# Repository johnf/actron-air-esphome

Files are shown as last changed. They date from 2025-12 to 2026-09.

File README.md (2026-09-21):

# Actron Air ESPHome Integration for Home Assistant

An ESPHome external component for reading and decoding pulse trains from the
Actron Air ESP32 keypad display, plus a Home Assistant integration with climate
entity and custom Lovelace card.

## Key Features

- **Interrupt-driven reading**: Accurate pulse train capture
- **40-bit decoding**: Full status from keypad display
- **Temperature display**: 7-segment decoder for setpoint
- **18 binary sensors**: Mode, fan, zones, timers
- **Error tracking**: Bit count for monitoring reliability
- **Type-safe config**: ESPHome validation for all settings
- **Climate entity**: Full HVAC control with zone presets
- **Custom Lovelace card**: Retro keypad-style control interface

## Hardware Requirements

- ESP32 (ESP-IDF framework, circuit below uses an ESP32-C3 Super Mini)
- GPIO pin for pulse train input
- Connection to air conditioner keypad display output
- MCP4725 or MCP4726 DAC (I2C) for keypad button emulation
- HW133 DC-DC converter to power the ESP from the keypad
- BC548 NPN transistor
- Resistors: 22kΩ, 4.7kΩ, 1.0kΩ (0.5W or higher)
- Diode: 1N5817
- Capacitor: 1000µF (25V or higher)

See the [forum thread](https://community.home-assistant.io/t/actron-aircon-esp32-controller-help/609062)
for detailed build instructions and wiring diagrams.

## Compatible Systems

This integration works with Actron Air ducted systems that use the older-style
wall controllers with a 4-wire interface (SENS, KEY, COMM, POWER).

### Wall Controllers

| Controller | Status | Notes |
|---|---|---|
| LM24 | Confirmed | Multi-zone controller |
| LM7 / LM7-2W / LM7-2G | Community reported | 7-day programmable, up to 8 zones |
| LM7-D | Community reported | Ultima Zone Control Master |
| AM7 | Community reported | Original older controller |

### Air Conditioner Systems

**Compatible:**

- SRA series (e.g., SRA22C, SRA25C) - older multi-zone ducted systems
- SRD series (e.g., SRD175C, SRD22C) - older ducted systems
- ESP Plus, ESP Platinum, ESP Ultima with LM7/LM24 controllers
- Classic series (SRG models) with LM7/LM24 controllers

**Not compatible:**

- Systems with QUE controllers (different architecture)
- Systems with ActronConnect/ACM WiFi modules (post-2013)
- Serene Series with Easy Connect app

## Installation

This project has two parts:

1. **ESPHome component** - Runs on your ESP32 to read the keypad and control the AC
2. **Home Assistant integration** - Provides climate entity and Lovelace card

**Set up the ESPHome device first**, then install the Home Assistant integration.

### Step 1: ESPHome Device Setup

See [ESPHome Configuration](#esphome-configuration) below for detailed setup instructions.
The quickest way is to use the ESPHome package - just copy
[example_actron_air_keypad.yaml](example_actron_air_keypad.yaml) and customise for your setup.

### Step 2: Home Assistant Integration

Once your ESPHome device is running, install the integration:

#### HACS (Recommended)



Or manually:

1. Open HACS in Home Assistant
2. Go to "Integrations" section
3. Click the three dots menu and select "Custom repositories"
4. Add `https://github.com/johnf/actron-air-esphome` with category "Integration"
5. Install "Actron Air ESPHome"
6. Restart Home Assistant
7. Go to Settings > Devices & Services > Add Integration
8. Search for "Actron Air ESPHome" and configure

The integration will automatically register the Lovelace card.

#### Manual Installation

1. Copy the `custom_components/actron_air_esphome` folder to your Home Assistant `config/custom_components/` directory
2. Restart Home Assistant
3. Go to Settings > Devices & Services > Add Integration
4. Search for "Actron Air ESPHome" and configure

## Lovelace Card Usage

Actron Air Card

Add the card to your dashboard:

```yaml
type: custom:actron-air-esphome-card
entity_prefix: actron_air
```

### Card Configuration Options

| Option | Type | Default | Description |
|---|---|---|---|
| `entity_prefix` | string | **required** | Prefix for ESPHome entities (e.g., `actron_air`) |
| `name` | string | - | Card title (optional) |
| `show_timer` | boolean | `true` | Show timer controls |
| `show_zones` | boolean | `true` | Show zone buttons |
| `zone_count` | number | `4` | Number of zones to display (1-7) |
| `zones` | array | - | Custom zone names |

### Full Configuration Example

```yaml
type: custom:actron-air-esphome-card
entity_prefix: actron_air
name: Air Conditioning
show_timer: true
show_zones: true
zone_count: 4
zones:
  - name: Bedrooms
  - name: Living Room
  - name: Kitchen
  - name: Office
```

### Expected Entity Names

The card expects entities with the following naming pattern based on your `entity_prefix`:

**Sensors:**

- `sensor.{prefix}_setpoint_temperature`

**Switches:**

- `switch.{prefix}_power`
- `switch.{prefix}_zone_1` through `switch.{prefix}_zone_8`

**Binary Sensors:**

- `binary_sensor.{prefix}_cool`
- `binary_sensor.{prefix}_heat`
- `binary_sensor.{prefix}_auto`
- `binary_sensor.{prefix}_run`
- `binary_sensor.{prefix}_fan_low`
- `binary_sensor.{prefix}_fan_mid`
- `binary_sensor.{prefix}_fan_high`
- `binary_sensor.{prefix}_fan_continuous`
- `binary_sensor.{prefix}_inside`
- `binary_sensor.{prefix}_timer`
- `binary_sensor.{prefix}_zone_1` through `binary_sensor.{prefix}_zone_8`

**Buttons:**

- `button.{prefix}_mode`
- `button.{prefix}_fan`
- `button.{prefix}_temp_up`
- `button.{prefix}_temp_down`
- `button.{prefix}_timer`
- `button.{prefix}_timer_up`
- `button.{prefix}_timer_down`

## ESPHome Configuration

The easiest way to get started is to use the ESPHome package, which includes all
sensors, DAC controls, and button definitions. See
[example_actron_air_keypad.yaml](example_actron_air_keypad.yaml) for a complete example.

### Quick Start (Using Package)

```yaml
packages:
  actron_air: github://johnf/actron-air-esphome/actron_air_keypad.yaml@main

esphome:
  name: "my-aircon"
  friendly_name: My Air Conditioner

wifi:
  ssid: !secret wifi_ssid
  password: !secret wifi_password

# Enable auto-discovery in Home Assistant
mdns:
  services:
    - service: "_actron_air"
      protocol: "_tcp"
      port: 6053
      txt:
        version: "1.0.0"
        name: "my-aircon"
```

That's it! The package includes everything you need:

- All 7 zones (remove unused ones with `!remove` if desired)
- DAC output for button emulation
- All binary sensors, switches, and buttons
- Configurable GPIO pins and voltage calibration via substitutions

### Customising the Package

Override any defaults by adding a `substitutions` section before the package:

```yaml
substitutions:
  gpio_keypad_pin: "GPIO32"    # Pin for keypad signal
  gpio_i2c_sda: "GPIO21"       # I2C SDA pin
  gpio_i2c_scl: "GPIO22"       # I2C SCL pin
  dac_output_address: "0x60"   # MCP4725 DAC I2C address
  # Voltage calibration (millivolts)
  voltage_zone_1: "725.0"
  voltage_zone_2: "663.0"
  # ... see actron_air_keypad.yaml for all options

packages:
  actron_air: github://johnf/actron-air-esphome/actron_air_keypad.yaml@main
```

### Removing Unused Zones

If you have fewer than 7 zones, you can remove the unused ones:

```yaml
packages:
  actron_air: github://johnf/actron-air-esphome/actron_air_keypad.yaml@main

# Remove zones 5-8 for a 4-zone system
switch:
  - id: !remove zone_5_switch
  - id: !remove zone_6_switch
  - id: !remove zone_7_switch
  - id: !remove zone_8_switch

  - id: !remove zone_5
  - id: !remove zone_6
  - id: !remove zone_7
  - id: !remove zone_8
```

### Manual Configuration (Without Package)

If you prefer more control, you can use the external component directly:

```yaml
external_components:
  - source:
      type: git
      url: https://github.com/johnf/actron-air-esphome
      ref: main
    components: [actron_air_esphome]

actron_air_esphome:
  pin: GPIO32

sensor:
  - platform: actron_air_esphome
    setpoint_temp:
      name: "Temperature"

binary_sensor:
  - platform: actron_air_esphome
    cool:
      name: "Cool Mode"
    heat:
      name: "Heat Mode"
    fan_high:
      name: "Fan High"
    zone_1:
      name: "Zone 1"
    zone_2:
      name: "Zone 2"
```

## Climate Entity

The Home Assistant integration provides a climate entity with:

- **HVAC Modes**: Off, Cool, Heat, Auto, Fan Only
- **Fan Modes**: High, Medium, Low, High Cont, Medium Cont, Low Cont, Off
- **Zone Presets**: Individual zones and "All Zones"
- **Optional**: Current temperature and humidity from external sensors

Configure via Settings > Devices & Services after installing the integration.

## Available ESPHome Sensors

### Numeric Sensors (`sensor` platform)

- `setpoint_temp` - Temperature from 7-segment display (C)
- `error_count` - Error counter for monitoring

### Status Sensors (`binary_sensor` platform)

- **Mode**: `cool`, `heat`, `auto_mode`, `run`
- **Fan**: `fan_high`, `fan_mid`, `fan_low`, `fan_cont`
- **Zones**: `zone_1` through `zone_8`
- **Other**: `inside`, `timer`

### Debug Sensors (`text_sensor` platform)

- `bit_string` - Raw 40-bit pulse train (internal use)

## How It Works

### Wires

There are 4 wires inside the wall unit that connect to the main supply:

- SENS - sensor line is directly connected to a thermistor
- KEY - connected to the keypad, it changes resistance to a different value
  when keys are pressed. This drops the voltage from 5V to different levels
- COMM - ground
- POWER - 19V and also data line that gets shifted into the LED. The protocol
  in this wire is quite simple: Data is transmitted every 200ms or so. It starts
  with a 16V->0V transition, followed by 41 other pulses, a zero or a one is
  determined by the time between the pulses. Each value is then shifted through
  the leds in the board.

### Pulse Train Decoding

1. An interrupt handler captures falling edges on the ADC pin
2. Timing between edges determines if the pulse represents a '0' or '1'
3. 40 bits are collected to form a complete frame
4. The frame is decoded to extract display and LED status
5. Changes are published to Home Assistant sensors

## Circuit Diagrams

The circuit connects the ESP32 to the Actron Air keypad interface. Fritzing source
files are available in the [fritzing/](fritzing/) directory.

### Schematic

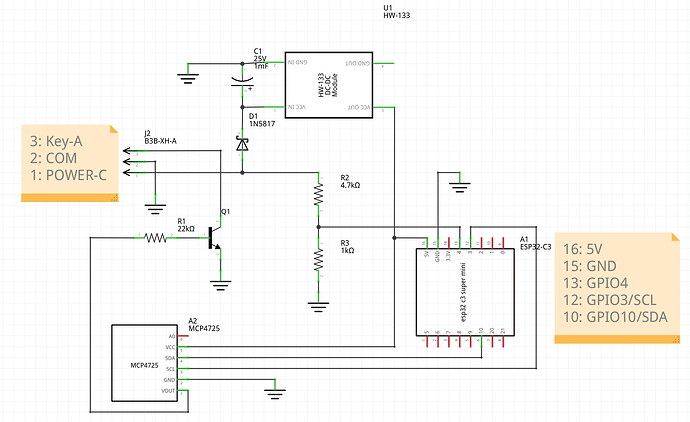
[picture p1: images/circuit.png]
Circuit Schematic


### Veroboard Layout

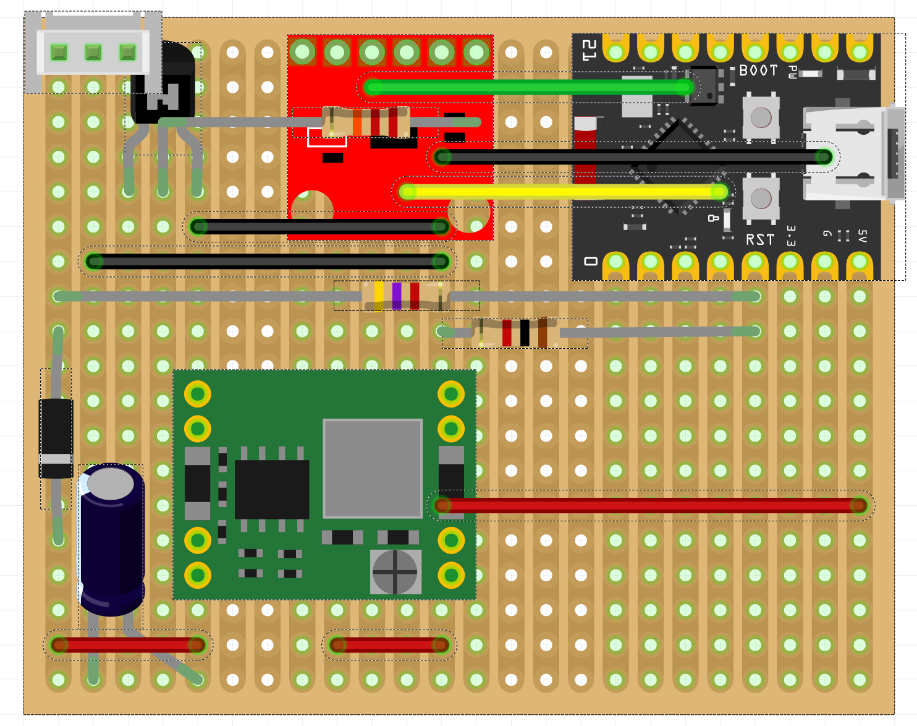
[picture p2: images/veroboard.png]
Veroboard Layout


## Troubleshooting

### No data received

- Check ADC pin connection
- Verify pulse train voltage levels
- Monitor `error_count` sensor for errors

### Incorrect temperature readings

- Check 7-segment wiring/decoding
- Look at `bit_string` for raw data
- Verify display is showing temperature

### Compile errors

- Ensure ESP-IDF framework is selected
- Check all Python files are present
- Validate YAML indentation

### Card not showing

- Clear browser cache
- Check browser console for errors
- Verify the resource is loaded in Settings > Dashboards > Resources

---

**Need Help?**

- Check ESPHome logs: `esphome logs your-device.yaml`
- Validate config: `esphome config your-device.yaml`
- Review example_actron_air_keypad.yaml for complete setup

## License

MIT License - Feel free to use and modify

## Thanks

This builds on the work of many others:

- <https://community.home-assistant.io/t/actron-aircon-esp32-controller-help/609062>
- <https://github.com/kursancew/actron-air-wifi>
- <https://github.com/brentk7/Actron-Keypad>
- <https://github.com/cjd/Actron-Keypad>
- <https://github.com/LaughingLogic/Actron-Keypad>

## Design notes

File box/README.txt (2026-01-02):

Box 02 (with rectangular and hexagonal ventilation holes) by jorgecasas on Thingiverse: https://www.thingiverse.com/thing:2004687

Modified by John Ferlito for this project

Summary:
Small box (parametrizable), with logo and ventilation holes (grid rectangular and hexagonal)

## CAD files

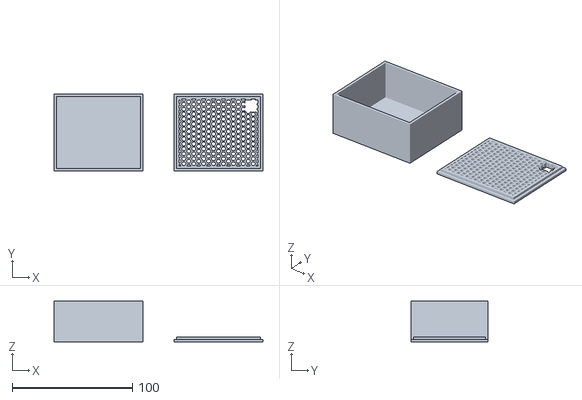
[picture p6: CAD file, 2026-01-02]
box/box-wemos-iternova.stl
174.0 x 64.0 x 34.0

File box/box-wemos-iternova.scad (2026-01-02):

// Dimensions
box_thick = 2;
box_width = 70 + 2 *  box_thick;
box_height = 60 + 2 *  box_thick;
box_depth = 30 + 2 *  box_thick;
connector_height = 10;
connector_width = 10;

// Bottom
difference() {
    // Parte exterior - interior (caja hueca)
    cube([box_width,  box_height,  box_depth]);
    translate([box_thick,  box_thick, 2 *  box_thick])
      cube([box_width - 2 * box_thick, box_height - 2 * box_thick, box_depth ]);
}

// Top
translate([100,0,0]) {
    difference() {
        // Tapa + reborde de tapa
        union() {
            cube([box_width, box_height, box_thick]);
            translate([box_thick, box_thick, 0])
              cube([box_width - 2 * box_thick, box_height- 2 * box_thick, 2 * box_thick]);
        }

        // Grid hexagonal tapa
        translate([box_thick + 1, box_thick + 1, -1])
          grid_hexagonal(box_width - (2 * box_thick), box_height - (2 * box_thick ), box_thick + 2, 16);
    
        // Connector hole - top right corner (with margin from edge)
translate([box_width - connector_width - box_thick - 3, box_height - connector_height - box_thick - 3, -1])
  cube([connector_width, connector_height, 2 * box_thick + 2]);
    }  
}
       

module grid_hexagonal(width, height, depth , hexagons_width) {    
    separation = (width / hexagons_width ) / 2.25;
    intersection() {
       // cube([width,height,depth], center = false);
        translate( [ separation / 2, separation / 2, 0] ) intersection() {
            array_hexagons(width - 4, height - 4, depth + 2, hexagons_width );
            cube([width - 4,height - 4,depth + 2], center = false);
        }
    }
}

/**
 * Create an array of hexagons
 */
module array_hexagons(width, height, depth, hexagons_width) {    
    separation = (width / hexagons_width);
    hexagons_height = (hexagons_width * height / width);
    radio = separation / 2.25;
    
    for( x = [ 0 : 1 : hexagons_width])
        for( y = [ 0 : 1 : hexagons_height ])
            translate([(x * separation), ( y + ( x % 2 )/2 ) * separation ,0])
                cylinder(h = depth, r1 = radio, r2 = radio, center = false , $fn = 6);

}

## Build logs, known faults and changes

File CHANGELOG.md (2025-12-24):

## [0.1.4](https://github.com/johnf/actron-air-esphome/compare/v0.1.3...v0.1.4) (2025-12-24)

### Bug Fixes

* modify load path for card registration [#3](https://github.com/johnf/actron-air-esphome/issues/3) ([3b6d908](https://github.com/johnf/actron-air-esphome/commit/3b6d9087fcef42e9b121fa2ee745dae154fa78ca))
* zone rendering location ([75965d7](https://github.com/johnf/actron-air-esphome/commit/75965d7d02e8ce8f1cc379385592dbc777271b5d))

## [0.1.3](https://github.com/johnf/actron-air-esphome/compare/v0.1.2...v0.1.3) (2025-12-24)

### Bug Fixes

* add integration type ([00d6ca0](https://github.com/johnf/actron-air-esphome/commit/00d6ca014bed215584a0997ca12084c9be4959b6))
* keep manifest.json updated ([5e00df8](https://github.com/johnf/actron-air-esphome/commit/5e00df8b643e7f9c56efc840927adfa06ade6363))

## [0.1.2](https://github.com/johnf/actron-air-esphome/compare/v0.1.1...v0.1.2) (2025-12-19)

### Bug Fixes

* be consistent in zone naming ([7a38b1e](https://github.com/johnf/actron-air-esphome/commit/7a38b1e8fe5cabb56431b40378be47fccf80169e))

## [0.1.1](https://github.com/johnf/actron-air-esphome/compare/v0.1.0...v0.1.1) (2025-12-19)

### Bug Fixes

* **ci:** use gh CLI to upload zip to existing release ([30d855a](https://github.com/johnf/actron-air-esphome/commit/30d855a07f12d564fcc0fdb51098d9927c0fe18c))

## [0.1.0](https://github.com/johnf/actron-air-esphome/compare/v0.0.14...v0.1.0) (2025-12-19)

### Features

* **esphome:** convert configuration to reusable package ([a987096](https://github.com/johnf/actron-air-esphome/commit/a987096c770cb002f84c5b46585b0af0b646708a))

## [0.0.14](https://github.com/johnf/actron-air-esphome/compare/v0.0.13...v0.0.14) (2025-12-19)

### Bug Fixes

* update git URL ([f37af84](https://github.com/johnf/actron-air-esphome/commit/f37af8409b59161f5b66f513698e741b853e771b))

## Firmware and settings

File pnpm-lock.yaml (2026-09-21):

---
lockfileVersion: '9.0'

importers:

  .:
    configDependencies: {}
    packageManagerDependencies:
      pnpm:
        specifier: 12.5.1
        version: 12.5.1

packages:

  '@pnpm/exe.android-arm64@12.5.1':
    resolution: {integrity: sha512-6LGBmQuDzUmgpHSuy+haG0jrmkwFNa4EuShDZqK3cIBv4Wfb75CzjJmowkzr+iJg40vnBKMQ62t4Ko6mwsId7A==}
    cpu: [arm64]
    os: [android]

  '@pnpm/exe.android-x64@12.5.1':
    resolution: {integrity: sha512-091oCltP3Rx89yxL1Wh5rXkUXEyFzyxIzSHKRFDyDFlQkb8Ox8FaDcm+M8PNkMyqnLA+qeGOLzY7Rjj9izl1Ww==}
    cpu: [x64]
    os: [android]

  '@pnpm/exe.darwin-arm64@12.5.1':
    resolution: {integrity: sha512-r1vEMQPVjRexZMyL2HonxJoo3+nuB/+G+tg+f2PK6faRdXX1TDwevKXOxJAfqlPInTy6W/pm912+s+m0NcR4BQ==}
    cpu: [arm64]
    os: [darwin]

  '@pnpm/exe.darwin-x64@12.5.1':
    resolution: {integrity: sha512-YHwI1g2B+Y2cAEylOR31r781GWijdJL7Gy7TEn/ZpZ5v/Cuwp5/Pz0EFCgo0M2MKLafAbL/laUMGvOpAdnerAw==}
    cpu: [x64]
    os: [darwin]

  '@pnpm/exe.freebsd-x64@12.5.1':
    resolution: {integrity: sha512-sFUMHiYFs6q5syFwgaVppzhQSmqnXoJIz/YwTXIOXTDE76ndIpTRpDGAnBCBKjsaEBnqjJA/2l6hpJcNDNoMiA==}
    cpu: [x64]
    os: [freebsd]

  '@pnpm/exe.linux-arm64-musl@12.5.1':
    resolution: {integrity: sha512-zupuxYZBuBEGjUz805/4/Asq01UNziFADANt8yp+LdUjU9bbMa3xY78Bx1PsGDqBy7aiad4sdUMK8ZxH4n4gmQ==}
    cpu: [arm64]
    os: [linux]
    libc: [musl]

  '@pnpm/exe.linux-arm64@12.5.1':
    resolution: {integrity: sha512-6hbMWW2/eQo1b5wvQPe/ndLHVTH88Rav6N+ffD4/h6IuFMjWCgasFYYsFv0GrvpqREAx3SwmZSvli+0NFXqbxA==}
    cpu: [arm64]
    os: [linux]
    libc: [glibc]

  '@pnpm/exe.linux-ppc64@12.5.1':
    resolution: {integrity: sha512-Gg3maDzaE/ZFMV9HIx/BwMN0Y6QbEs13URfxmiYHtKjjLAs5wEQZRMUP87YNLYO7cNaEfbM8GRbS9vPosyD9Gw==}
    cpu: [ppc64]
    os: [linux]
    libc: [glibc]

  '@pnpm/exe.linux-riscv64@12.5.1':
    resolution: {integrity: sha512-6fgWxXYMBMsWQ8DAiRevscX4QZQjwh+FsyCj8ZOk8pMXvqeq84MqBLCmS6KckvnbdqJ+HlSVQ7fs/kd0ldwfhA==}
    cpu: [riscv64]
    os: [linux]
    libc: [glibc]

  '@pnpm/exe.linux-s390x@12.5.1':
    resolution: {integrity: sha512-nzMZruRvxDhEfYUhzu+7EmM39+82Dgagc/6hPFPqGqzXNGcIG0anuxbUxfeNtI64SHt91KuuYUmCB/inlM+Pag==}
    cpu: [s390x]
    os: [linux]
    libc: [glibc]

  '@pnpm/exe.linux-x64-musl@12.5.1':
    resolution: {integrity: sha512-kHCbegdTNHpzmPtUD4S5fqkVkqgdQR47spF9p2VPP3dIIkZl6Ytk8w0vhlAsAGgge8FmucfwX+vvPKgm0NtOCQ==}
    cpu: [x64]
    os: [linux]
    libc: [musl]

  '@pnpm/exe.linux-x64@12.5.1':
    resolution: {integrity: sha512-3PkUBYo5z4dgtlnTNIFj7QGpcDUAuqXz9WGVigPDCeccEnhGiRkWmA5102TmYJHtwJP3LfmE+ZF9PGeWhn8p9Q==}
    cpu: [x64]
    os: [linux]
    libc: [glibc]

  '@pnpm/exe.win32-arm64@12.5.1':
    resolution: {integrity: sha512-49NvjZIXHly56/PLoEDD7VphbO4N8dwMXoApElDFCpVGDNGeKlwlib1tXtnpTF6i2/XIsAj7GgatHB5KHXgBnA==}
    cpu: [arm64]
    os: [win32]

  '@pnpm/exe.win32-x64@12.5.1':
    resolution: {integrity: sha512-ePUmQFPAPJFNMwg1lelDx2PdjHqYRiF0yfg5e6qeDbPNOu97QNo557Ru/SxmCrmt8ydQWNuZXWpdEp019md5vw==}
    cpu: [x64]
    os: [win32]

  pnpm@12.5.1:
    resolution: {integrity: sha512-4/MFvHhKK8ifWtO2E4iJRw+ujSr182thIW7JHCw9ZAiXdfneOKrDMQROpA8kXLDVZmOS399lgk4ZB+9qLGLeXw==}
    engines: {node: '>=18.*'}
    hasBin: true

snapshots:

  '@pnpm/exe.android-arm64@12.5.1':
    optional: true

  '@pnpm/exe.android-x64@12.5.1':
    optional: true

  '@pnpm/exe.darwin-arm64@12.5.1':
    optional: true

  '@pnpm/exe.darwin-x64@12.5.1':
    optional: true

  '@pnpm/exe.freebsd-x64@12.5.1':
    optional: true

  '@pnpm/exe.linux-arm64-musl@12.5.1':
    optional: true

  '@pnpm/exe.linux-arm64@12.5.1':
    optional: true

  '@pnpm/exe.linux-ppc64@12.5.1':
    optional: true

  '@pnpm/exe.linux-riscv64@12.5.1':
    optional: true

  '@pnpm/exe.linux-s390x@12.5.1':
    optional: true

  '@pnpm/exe.linux-x64-musl@12.5.1':
    optional: true

  '@pnpm/exe.linux-x64@12.5.1':
    optional: true

  '@pnpm/exe.win32-arm64@12.5.1':
    optional: true

  '@pnpm/exe.win32-x64@12.5.1':
    optional: true

  pnpm@12.5.1:
    optionalDependencies:
      '@pnpm/exe.android-arm64': 12.5.1
      '@pnpm/exe.android-x64': 12.5.1
      '@pnpm/exe.darwin-arm64': 12.5.1
      '@pnpm/exe.darwin-x64': 12.5.1
      '@pnpm/exe.freebsd-x64': 12.5.1
      '@pnpm/exe.linux-arm64': 12.5.1
      '@pnpm/exe.linux-arm64-musl': 12.5.1
      '@pnpm/exe.linux-ppc64': 12.5.1
      '@pnpm/exe.linux-riscv64': 12.5.1
      '@pnpm/exe.linux-s390x': 12.5.1
      '@pnpm/exe.linux-x64': 12.5.1
      '@pnpm/exe.linux-x64-musl': 12.5.1
      '@pnpm/exe.win32-arm64': 12.5.1
      '@pnpm/exe.win32-x64': 12.5.1

---
lockfileVersion: '9.0'

settings:
  autoInstallPeers: true
  excludeLinksFromLockfile: false
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

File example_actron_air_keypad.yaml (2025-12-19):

esphome:
  name: "esphome-web-aircon"
  comment: "ESPHome configuration for AirCon Keypad"
  area: Hallway
  friendly_name: ESPHome - Actron Air
  min_version: 2025.11.0
  name_add_mac_suffix: false

esp32:
  variant: esp32
  framework:
    type: esp-idf

# Enable logging
logger:

# Enable Home Assistant API
api:

# Allow Over-The-Air updates
ota:
  - platform: esphome

wifi:
  ssid: !secret wifi_ssid
  password: !secret wifi_password
  ap:
    ssid: "Aircon-Keypad Fallback Hotspot"
    password: !secret wifi_ap_password

captive_portal:

web_server:
  port: 80

# Enable auto-discovery in Home Assistant
mdns:
  services:
    - service: "_actron_air"
      protocol: "_tcp"
      port: 6053
      txt:
        version: "1.0.0"
        name: "esphome-web-aircon"

# Setup i2c bus to controll MCP4725
i2c:
  sda: GPIO21
  scl: GPIO22

# MCP4725 output to send voltages for key presses
output:
  - platform: mcp4725
    id: dac_output

globals:
  - id: dac_value
    type: double
  - id: prev_fan
    type: std::string
    initial_value: '"Unset"'
  # DAC voltage values for button presses (in millivolts)
  - id: voltage_power
    type: double
    initial_value: "5000.0"
    # Panel: 0
  - id: voltage_fan
    type: double
    initial_value: "755.0"
  - id: voltage_mode
    type: double
    initial_value: "620.0"
  - id: voltage_temp_up
    type: double
    initial_value: "889.0"
  - id: voltage_temp_down
    type: double
    initial_value: "782.0"
  - id: voltage_timer
    type: double
    initial_value: "862"
  - id: voltage_timer_up
    type: double
    initial_value: "828.0"
  - id: voltage_timer_down
    type: double
    initial_value: "808.0"
  - id: voltage_zone_1
    type: double
    initial_value: "725.0"
  - id: voltage_zone_2
    type: double
    initial_value: "663.0"
  - id: voltage_zone_3
    type: double
    initial_value: "695.0"
  # NOTE: Add more zones as needed

# Testing: DAC output control
number:
  - platform: template
    name: "DAC Output milliVolts"
    icon: mdi:flash-triangle
    min_value: 0
    max_value: 5000
    step: 0.1
    optimistic: true
    on_value:
      then:
        lambda: |-
          id(dac_output).set_level((x / 5000.0));

# Internal button for press action
button:
  - platform: template
    name: "Press"
    id: press_button
    internal: true
    icon: mdi:power
    on_press:
      - logger.log: Button Pressed
      - lambda: |-
          id(dac_output).set_level((id(dac_value) / 5000.0));
      - delay: 250ms
      - lambda: |-
          id(dac_output).set_level((0.0 / 5000.0));
      - delay: 250ms

  - platform: template
    name: "Fan"
    icon: mdi:fan
    on_press:
      - lambda: |-
          id(dac_value)=id(voltage_fan);
          id(press_button).press();

  - platform: template
    name: "Mode"
    icon: mdi:air-conditioner
    on_press:
      - lambda: |-
          id(dac_value)=id(voltage_mode);
          id(press_button).press();

  - platform: template
    name: "Temp Up"
    icon: mdi:thermometer-plus
    on_press:
      - lambda: |-
          id(dac_value)=id(voltage_temp_up);
          id(press_button).press();

  - platform: template
    name: "Temp Down"
    icon: mdi:thermometer-minus
    on_press:
      - lambda: |-
          id(dac_value)=id(voltage_temp_down);
          id(press_button).press();

  - platform: template
    name: "Timer"
    icon: mdi:timer
    on_press:
      - lambda: |-
          id(dac_value)=id(voltage_timer);
          id(press_button).press();

  - platform: template
    name: "Timer Up"
    icon: mdi:timer-plus
    on_press:
      - lambda: |-
          id(dac_value)=id(voltage_timer_up);
          id(press_button).press();

  - platform: template
    name: "Timer Down"
    icon: mdi:timer-minus
    on_press:
      - lambda: |-
          id(dac_value)=id(voltage_timer_down);
          id(press_button).press();
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

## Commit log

2025-12-13 feat: initial ESPHome component for Actron Air keypad display
    Add external component to decode 40-bit pulse trains from Actron Air
    ESP32 keypad displays. Provides temperature setpoint, mode indicators,
    fan speed, and zone status as Home Assistant sensors via interrupt-driven
    GPIO capture and 7-segment decoding.
2025-12-13 fix: remove log from interrupt
2025-12-13 fix: timer bug
2025-12-14 refactor: improve code quality and modernise ESPHome component
    - Add type hints and docstrings to Python config files
    - Rename bit_count sensor to error_count for clarity
    - Rename filter binary sensor to inside
    - Remove zone8 (not present on keypad)
    - Convert LED indices to enum class LedIndex for type safety
    - Add timing namespace for protocol constants
    - Improve interrupt handling with proper null checks
    - Add destructor with interrupt cleanup
    - Fix volatile increment for C++20 compatibility
    - Use InterruptLock for safe ISR/main-loop data access
    - Replace std::stof with arithmetic to avoid exception risk
    - Add wire protocol documentation and attribution to README
    [example_actron_air_keypad.yaml]
2025-12-14 fix: switch back to 40 bits
2025-12-15 feat: add circuit diag image
2025-12-18 refactor: merge LedProtocol into ActronAirKeypad class
    Consolidate protocol decoding logic directly into the main component class,
    eliminating the separate led_protocol.h/cpp files. This simplifies the
    architecture by removing an unnecessary abstraction layer while maintaining
    identical functionality.
2025-12-19 feat: add zeroconf auto-discovery for Home Assistant integration
    ESPHome devices advertising the _actron_air._tcp mDNS service will now
    be automatically discovered by Home Assistant. Users can add the mdns
    service configuration to their ESPHome YAML to enable this feature.
    - Add zeroconf discovery to manifest.json
    - Add async_step_zeroconf and discovery_confirm flow to config_flow.py
    - Add discovery_confirm step strings and translations
    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
2025-12-19 fix: switch to zip release
2025-12-30 feat: add configurable I2C address for MCP4725 DAC
    Add dac_output_address substitution to allow overriding the default
    0x60 I2C address for the MCP4725 DAC. Update README with the new
    configuration option.
2026-01-02 docs: add circuit diagrams section to README
    Add documentation for the schematic and veroboard layout images,
    with reference to Fritzing source files. Replace old circuit image
    with updated schematic and new veroboard layout.
2026-01-02 docs: Add STL print for box
    [box-wemos-iternova.scad, box-wemos-iternova.stl]
2026-03-31 docs: update component list with components and values from circuit diagram
2026-10-27 fix: initialise pulses_ to ~0ULL sentinel to avoid dropped first frame
    When all 40 decoded bits are zero, the first valid frame would match the
    initial value of pulses_ (0) and has_new_data_ would never be set, silently
    dropping the frame. Using ~0ULL as a sentinel ensures the first real frame
    is always published.
2026-10-27 fix: decode keypad frames reliably
    Captured the keypad line with an RMT receiver alongside the ISR and found
    three ways the decoder misread frames:
    - The ~2.9ms start gap is absent whenever the timer LED is lit. The bit
    buffer was only cleared on that gap, so stale 1s accumulated and every
    sensor read wrong while a timer was set.
    - A ~1us bounce on a rising edge adds a falling edge 62us after the real
    one, giving 41 edges and a rejected frame (~6% of frames).
    - Occasionally a mistimed frame is accepted once, e.g. during a button
    press. This matches the one-frame false power-ons seen in Home Assistant.
    Any gap of 2.7ms or more now starts a new frame, edges within 250us of
    the last a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
2026-10-27 fix: queue key presses so they cannot overlap
    Every key set a shared dac_value global and pressed one internal button,
    so two presses less than ~0.5s apart ran concurrently and the second
    overwrote the first's voltage: a Temp Down followed 20ms later by a Zone
    3 press was seen to drop the Temp Down entirely.
    Keys now run a queued press_key script that takes the voltage as a
    parameter, so presses happen one after another with 250ms down and
    250ms released.
